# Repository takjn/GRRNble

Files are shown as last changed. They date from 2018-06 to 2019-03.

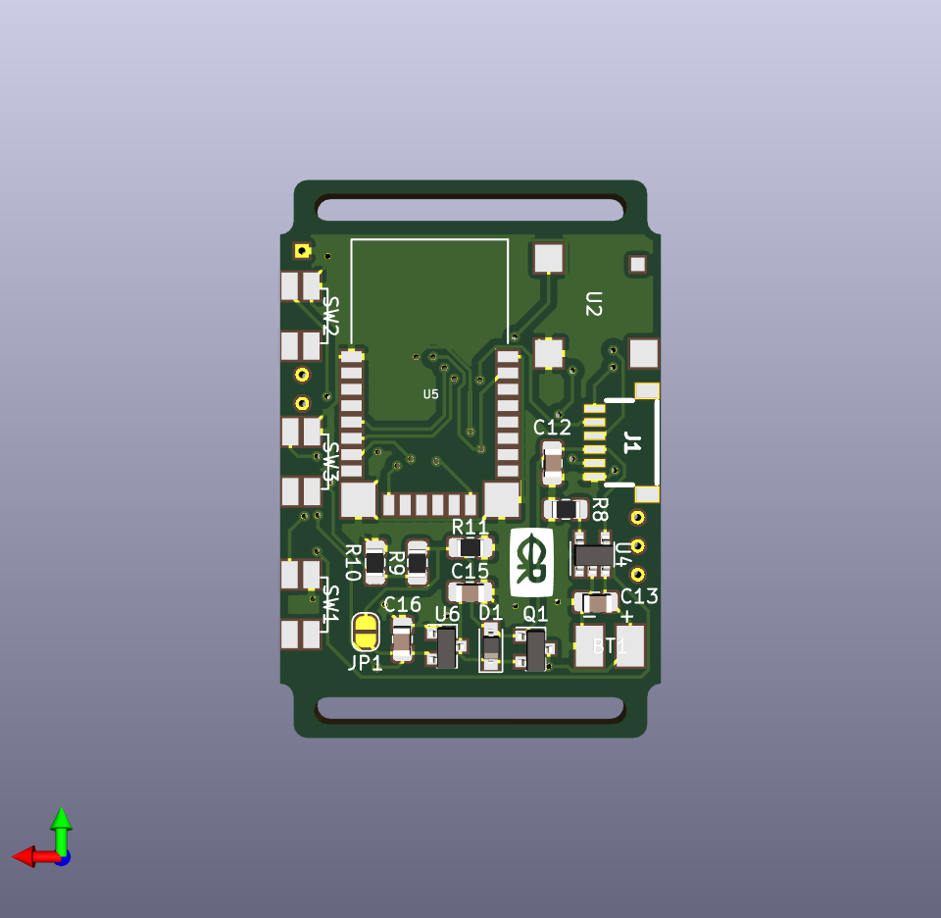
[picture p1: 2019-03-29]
pdf/back.png

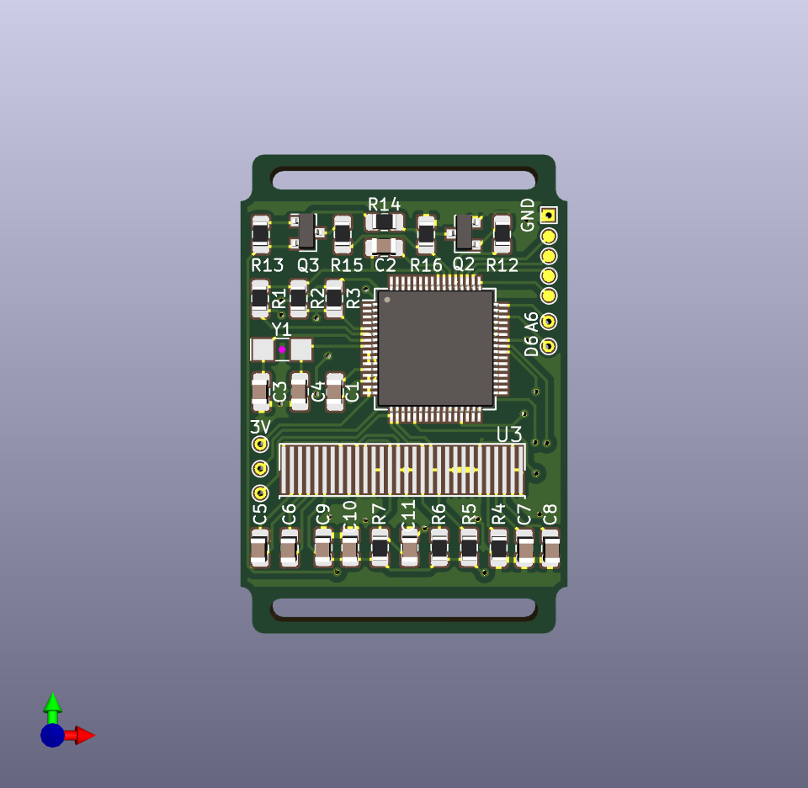
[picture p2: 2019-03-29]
pdf/front.png

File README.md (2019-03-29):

# GRRNble

DIY Smartwatch using Renesas RL78/G13 MCU and RN4020 ble module with Android companion app.

DIY Smartwatch (https://www.youtube.com/watch?v=k7GzKx2PxCo)

## Specification
### Hardware

- RL78/G13 32MHz (R5F100LJAFB 64pin LFQFP)
- ROM/RAM: 256KB/20KB
- 0.96″ 128x64 OLED display
- RN4020 Bluetooth Low Energy module
- RTC
- Buzzer
- Measuring battery voltage
- Li-Polymer Charging circuit

### Software

- Arduino like [IDE for GR](http://gadget.renesas.com/en/product/ide4gr.html) based smartwatch app
- [Android companion app](https://play.google.com/store/apps/details?id=com.github.takjn.grrnble)

## Hardware
### Schematic diagram
There is a KiCad project file in KiCad folder. Also, you can see the schematic pdf file in pdf folder.

### Parts list
All capacitors and resistors are 0805 (2012) SMD.

| Reference(s) | Value | Qty | Note |
|:---|:---|:---|:---|
|C1|0.47uF|1|I used 1.0uF insted.|
|C2, C11|0.1uF|2||
|C3, C4|15pF|2||
|C5, C6, C9, C10, C15, C16|1.0uF|6||
|C7, C12, C13|4.7uF|3||
|C8|2.2uF|1|I used 4.7uF insted.|
|R1|1k|1||
|R2|12k|1||
|R3|2k|1||
|R4|390k|1||
|R5, R6, R7, R13|10k|4||
|R8|22k|1||
|R9, R10|47k|2||
|R11|100k|1||
|R12, R14|100R|2||
|R15|7K5|1||
|R16|2K7|1||
|D1|CUS10F30|1||
|Q1, Q3|DMG3415U|2|P-ch FET|
|Q2|BSS138|1|N-ch FET|
|SW1, SW3, SW2|SKSCLAE010|3|ALPS Side Push switch|
|U1|R5F100LJAFB|1|RL78/G13 64pin|
|U2|UGCT7525AN4|1|Buzzer|
|U3|SSD1306|1|OLED 128x64 0.96 inch|
|U4|MCP73831-2-OT|1|Li-Polymer Charge Management Controller|
|U5|RN4020|1|Bluetooth Low Energy module|
|U6|MCP1703A-3302|1|LDO Regulator|
|Y1|FC-135|1|EPSON 3.2 x 1.5 x 0.80mm 32.768k crystal|
|BT1|Li-Po battery|1|3.7V/40mAh|
|J1|JST SH/1.0 6pin connector|1|JST 1.0mm pitch connector|
|-|JST SH/1.0 6pin cable|1|JST 1.0mm pitch terminal cable|
|-|FT232R / FT231X USB to serial adapter|1||

## Software

### RN4020 setup app

RN4020 can be setup with a special program and serial monitor.
Open RN4020Setup folder with [IDE for GR](http://gadget.renesas.com/en/product/ide4gr.html).
Connect your board and select GR-Cotton from "Tools" -> "Board" in the menu.
Compile the program and upload it to the board.

After uploading the sketch, select the port from "Tools" -> "Serial Port" in the menu and open Serial monitor.

### Smartwatch app

Open GRRNble folder with [IDE for GR](http://gadget.renesas.com/en/product/ide4gr.html).
Connect your board and select GR-Cotton from "Tools" -> "Board" in the menu.
Compile the program and upload it to the board.

### Android companion app

You need to have a development environment with Android Studio to build the Android App in the Android folder.

If you don't want to build from source files, you can install the compiled app from [Google Play](https://play.google.com/store/apps/details?id=com.github.takjn.grrnble).

## References
### Libraries
- [https://github.com/greiman/SSD1306Ascii](https://github.com/greiman/SSD1306Ascii)
- [https://github.com/Tamakichi/Arduino-misakiUTF16](https://github.com/Tamakichi/Arduino-misakiUTF16)

### Useful information (EN)
- [Gadget Renesas](http://gadget.renesas.com/en/)
- [GR-COTTON schematic diagram](http://gadget.renesas.com/ja/product/documents/gr-cotton_sch.pdf)
- [RN4020 Bluetooth® Low Energy Module User’s Guide](http://ww1.microchip.com/downloads/en/devicedoc/70005191b.pdf)
- [MCP1703A](http://akizukidenshi.com/download/ds/microchip/mcp1703a.pdf)
- [Designing A Li-Ion Battery Charger and Load Sharing System With
Microchip’s Stand-Alone Li-Ion Battery Charge Management Controller](http://ww1.microchip.com/downloads/en/appnotes/01149c.pdf)

### Useful information (JA)
- [Gadget Renesas](http://gadget.renesas.com/jp/)
- [GR-COTTON回路図](http://gadget.renesas.com/ja/product/documents/gr-cotton_sch.pdf)
- [RL78/G13 低消費電力動作編](https://www.renesas.com/jp/ja/doc/products/mpumcu/apn/rl78/001/r01an0465jj0210_rl78.pdf)
- [RN4020 Bluetooth® Low Energy モジュールユーザガイド](http://akizukidenshi.com/download/ds/microchip/70005191A_JP.pdf)
- [MCP1703A](http://akizukidenshi.com/download/ds/microchip/mcp1703a.pdf)
- [マイクロチップのスタンドアロンリチウムイオンバッテリ充電管理コントローラを使用したリチウムイオンバッテリ充電回路および負荷分担システムの設計](http://ww1.microchip.com/downloads/en/AppNotes/DS01149C_JP_battery.pdf)
- [BLE通信ソフトを作る ( Android Studio 2.3.3 + RN4020 )](http://www.hiramine.com/programming/blecommunicator/index.html)
- [KiCadで雑に基板を作る チュートリアル](https://www.slideshare.net/soburi/kicad-53622272)

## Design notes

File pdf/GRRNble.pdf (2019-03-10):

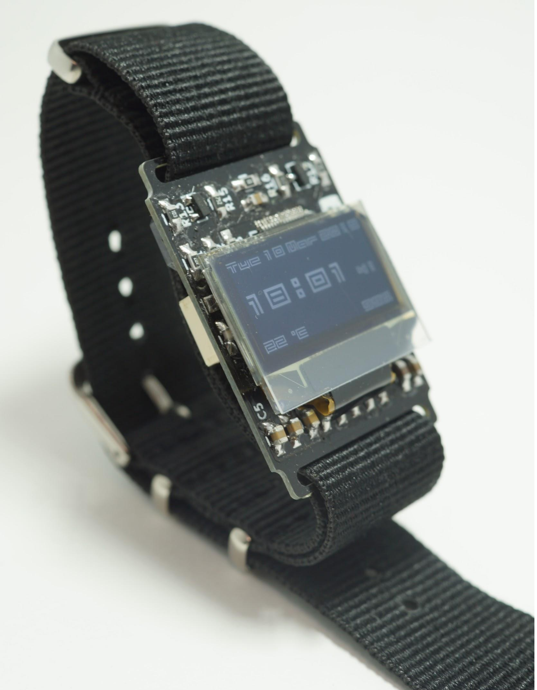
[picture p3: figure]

# DIY Smartwatch

### GRRNble Gen2

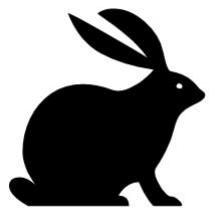
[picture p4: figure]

# @takjn

### https://github.com/takjn/GRRNble

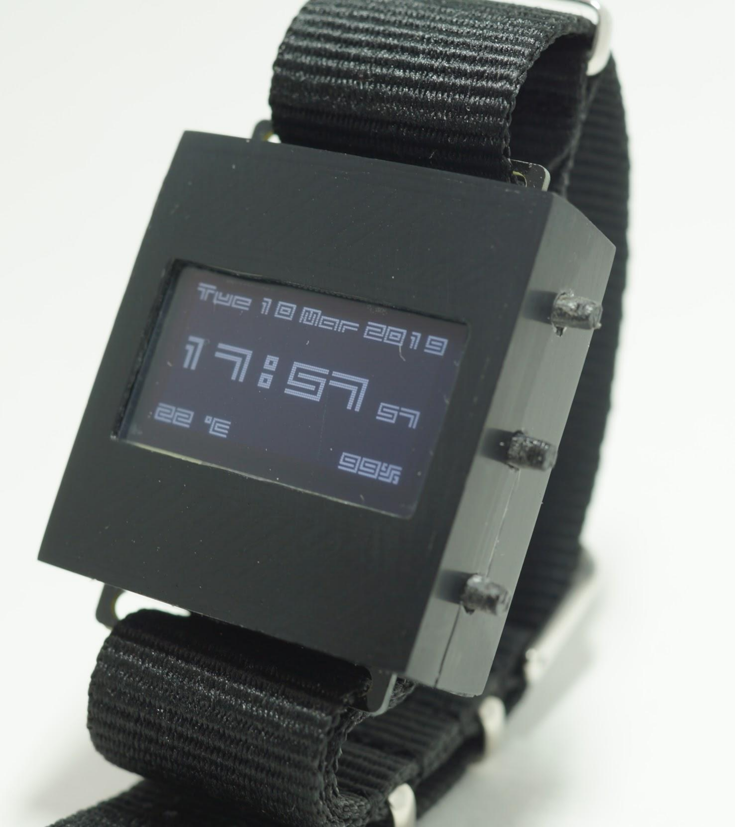
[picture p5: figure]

# Specification

### - RL78/G13 (R5F100LJAFB 64pin) - OLED (SSD1306), BLE (RN4020) - GR-COTTON ベースの基板 - IDE for GR で書き込み可能

- 3Dプリンターによる筐体
- Androidアプリと連携した通知
- バッテリーは1日は持つ

# Gen2 - 細かい点を色々と改良

### •RN4020 (BLE) の処理をポーリングから割り込みに変更

## •SSD1306 (OLED) の消費電力削減

### •ケースの改良 - 3Dプリント + UVレジンによるコーティング

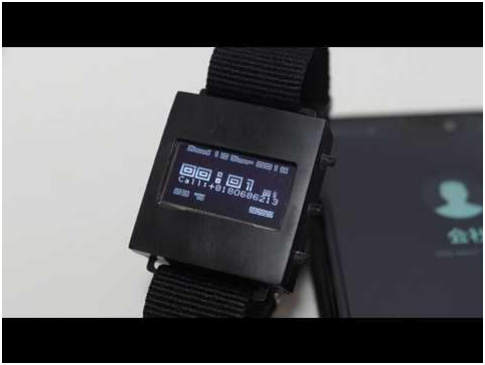
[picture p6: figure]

## Demonstration

https://youtu.be/k7GzKx2PxCo

- 電話の着信通知
- メニュー
- スタンバイ画面

# Hardware

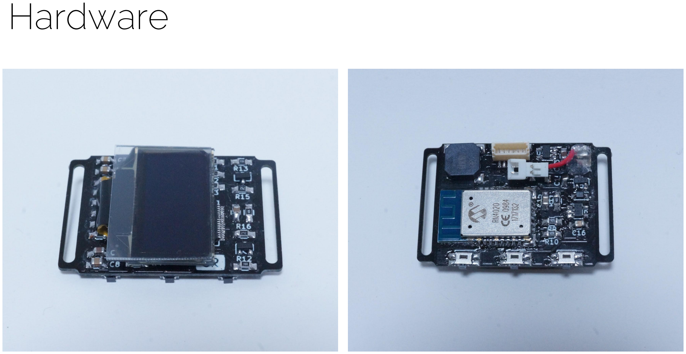
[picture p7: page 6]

# Software

## - RN4020 は deep sleep mode で待機

- スクリプト機能を活用してキャラクタリスティックをIOポートに紐付け
- スマホアプリからの受信でデジタルIOピンを HIGH にできる (割り込み)
- 受信内容はRN4020が保持しているのでマイコンが復帰後に Read できる

## - RL78/G13 は PM_STOP_MODE で待機

- delay()関数を実行しながらループで待機する
- RN4020 からの割り込みで復帰し、受信した結果を Read する
- ディスプレイ (OLED) の消費電力削減が課題

# Watch Case

### - 3Dプリンターで作成し、表面をUVレジンでコーティング

### - UVレジンを使うことで簡単に積層痕を消すことができる

- 3Dプリントしたものに軽くヤスリをかける
- UVレジンを厚塗りする (積層痕を埋める)
- UVランプでUVレジンを固めた後、紙ヤスリとコンパウンドで磨く (#240, #400, #800, #1200, #2000, 細目, 仕上げ目)

### - 磨きやすい硬さなので、簡単に仕上がる

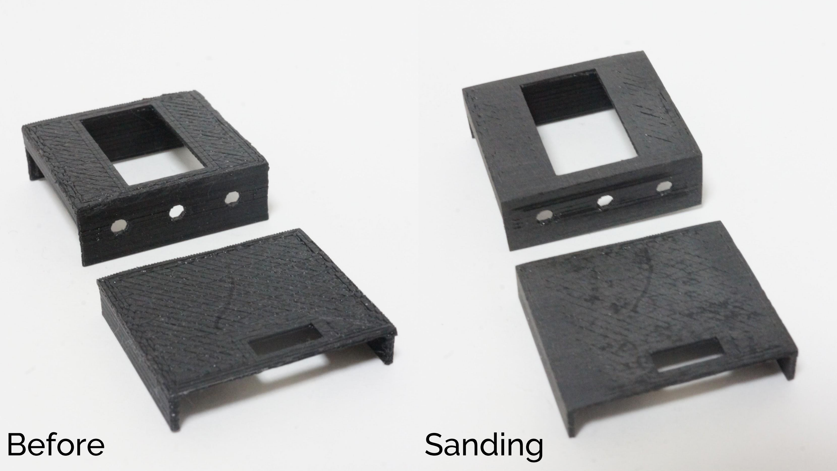
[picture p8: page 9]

Before | Sanding

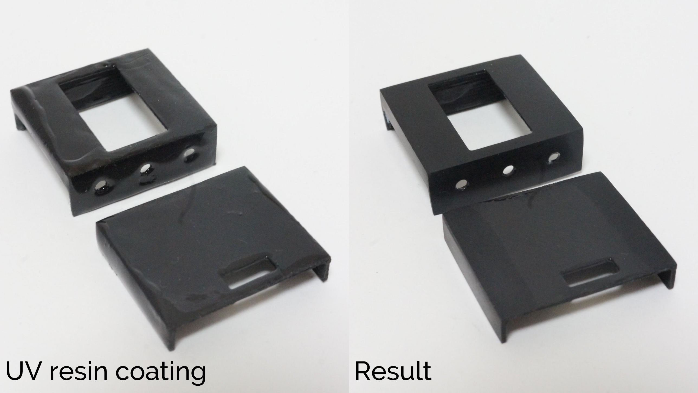
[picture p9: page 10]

UV resin coating | Result

# DIY Smartwatch

### GRRNble Gen2

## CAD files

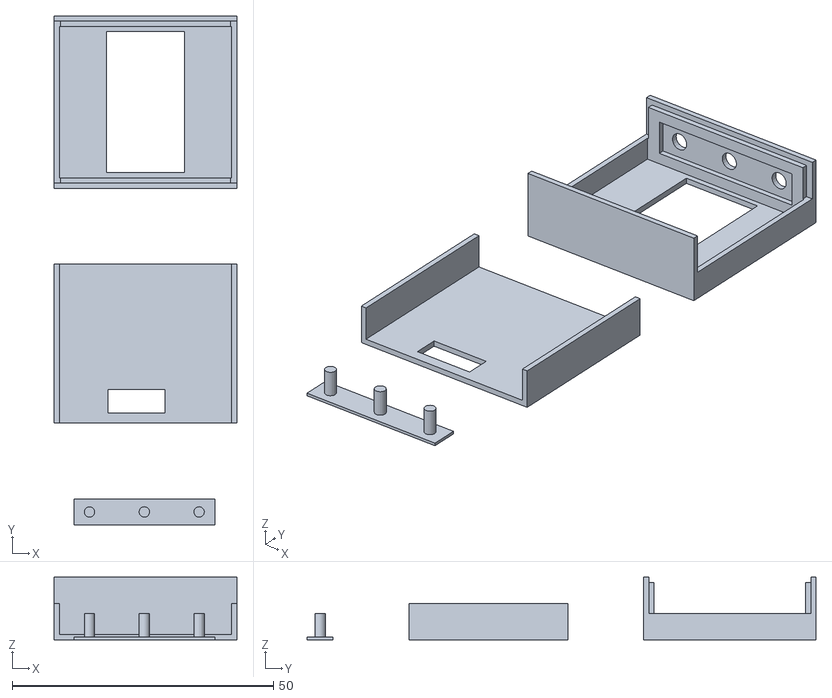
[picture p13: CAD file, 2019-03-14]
stl/GRRNble.stl
35.0 x 97.5 x 12.0

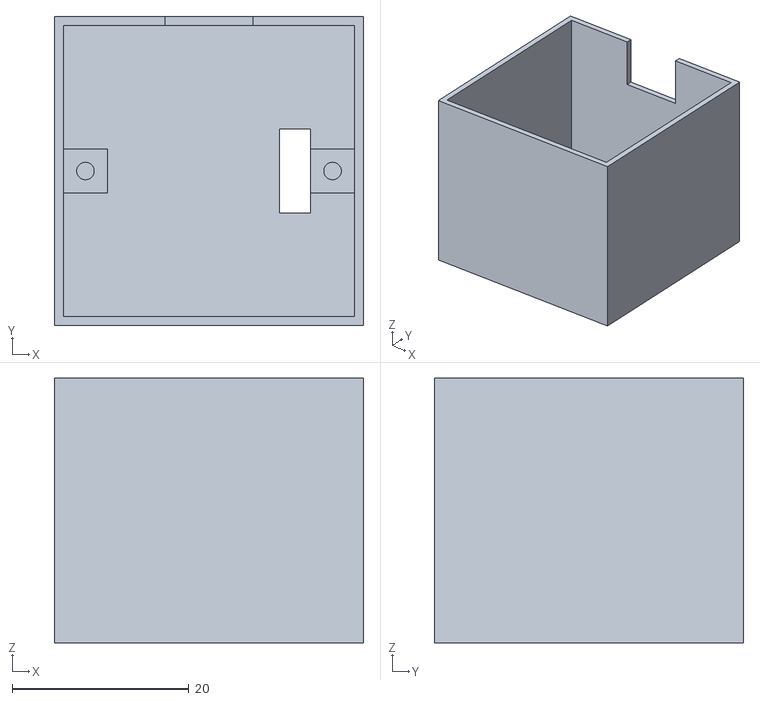
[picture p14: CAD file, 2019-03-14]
stl/GRRNbleCase.stl
35.0 x 35.0 x 30.0

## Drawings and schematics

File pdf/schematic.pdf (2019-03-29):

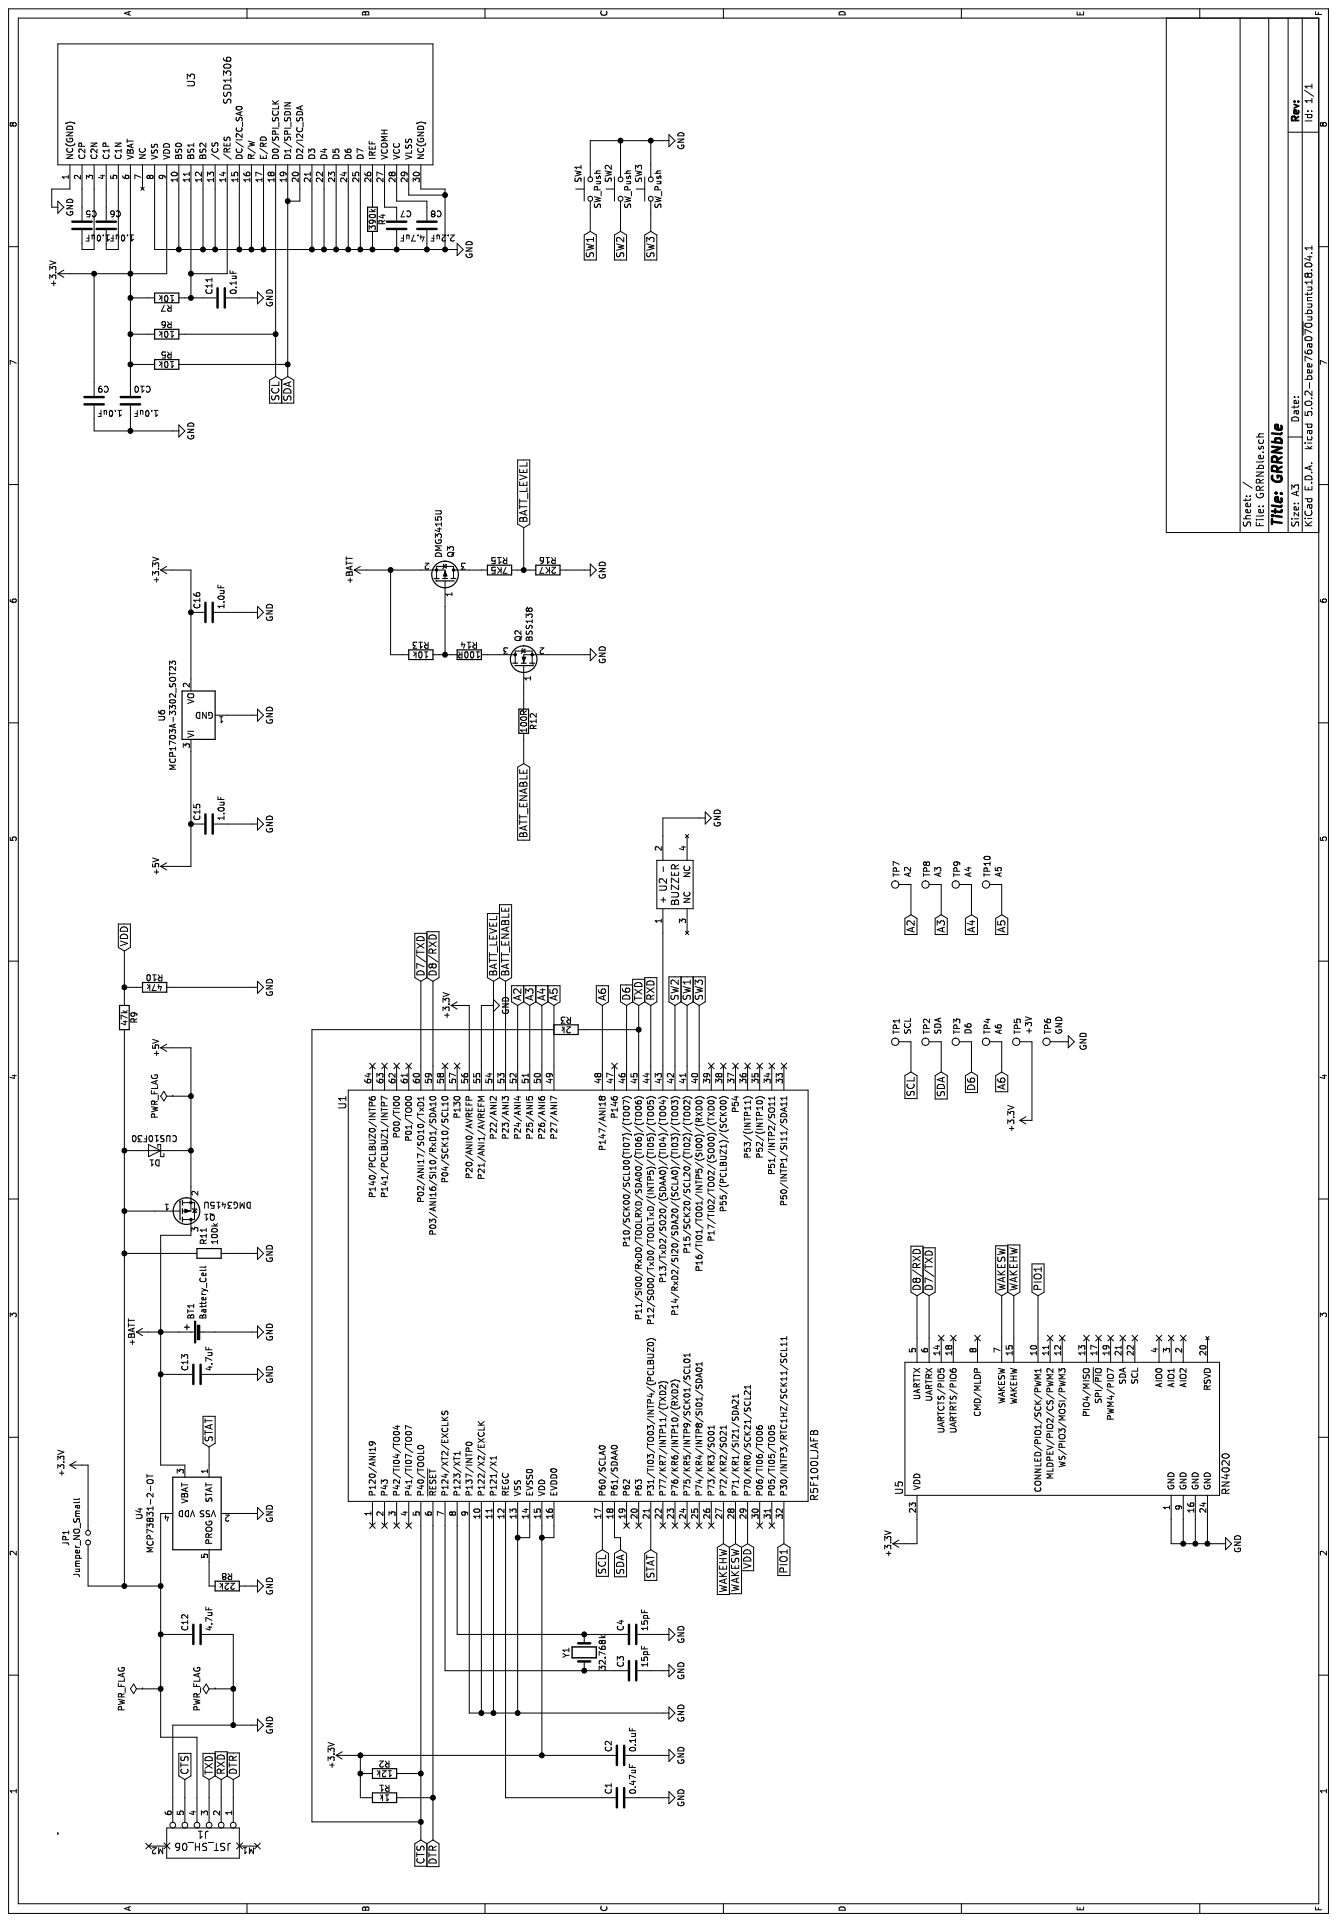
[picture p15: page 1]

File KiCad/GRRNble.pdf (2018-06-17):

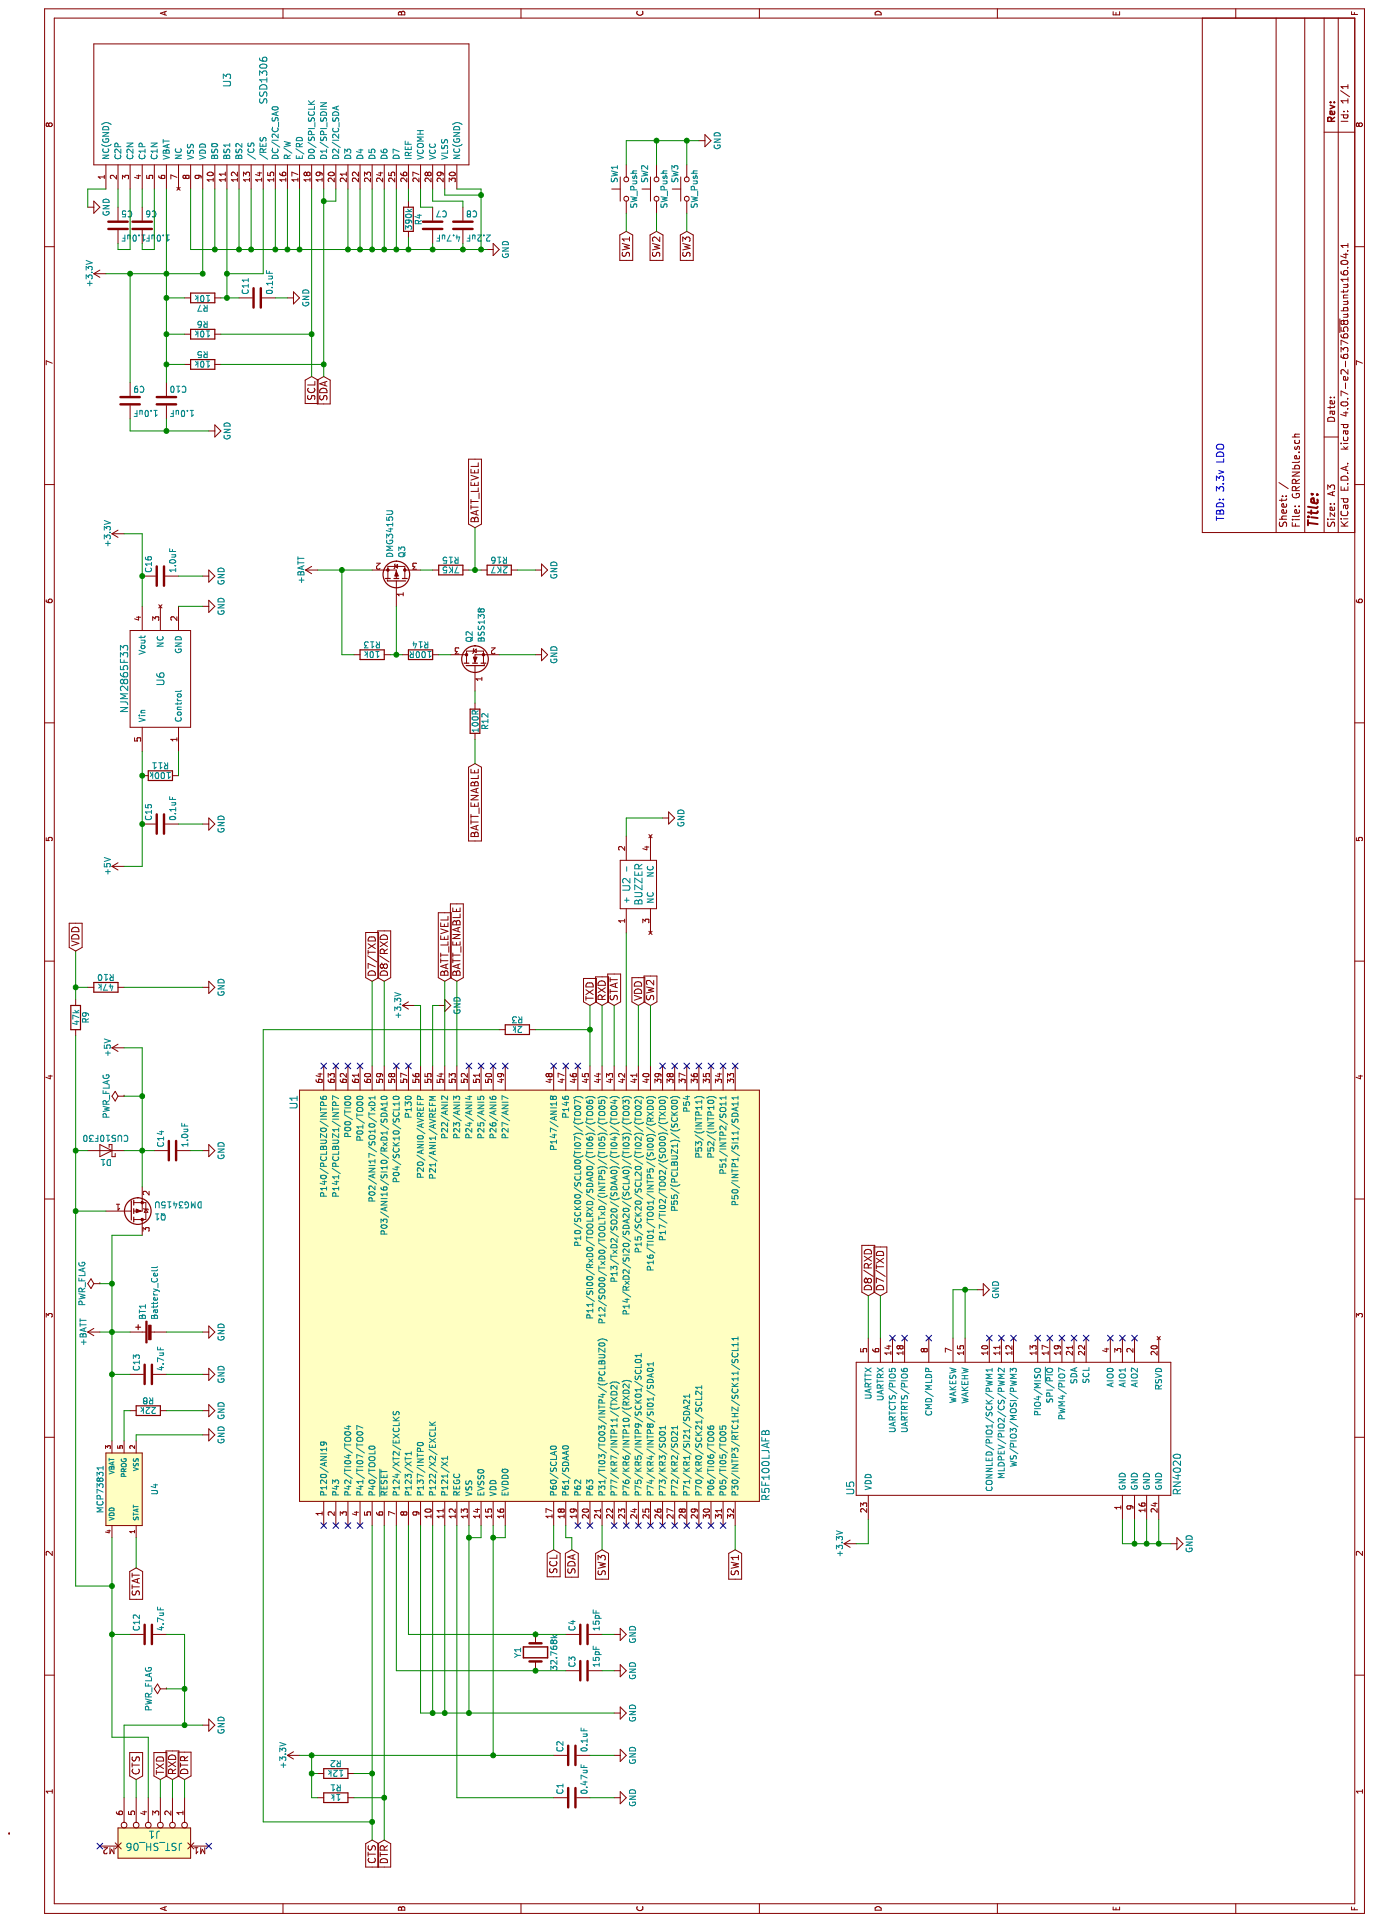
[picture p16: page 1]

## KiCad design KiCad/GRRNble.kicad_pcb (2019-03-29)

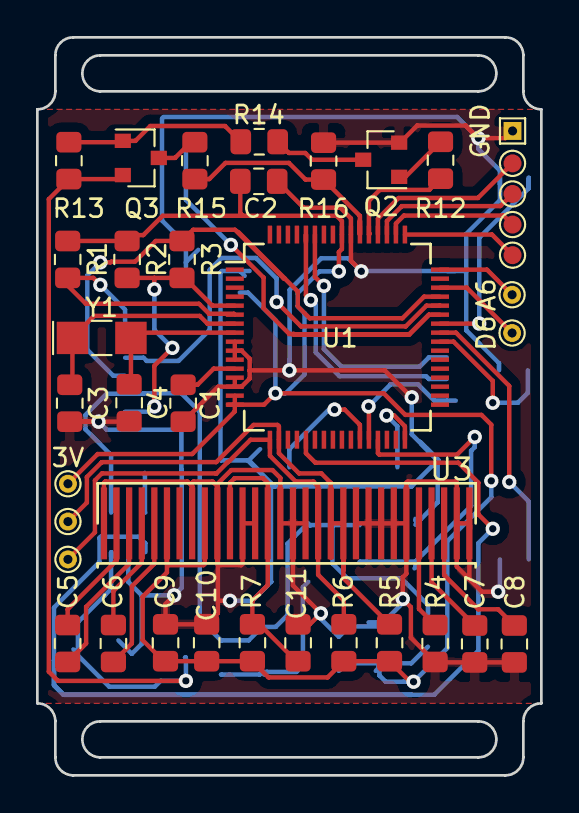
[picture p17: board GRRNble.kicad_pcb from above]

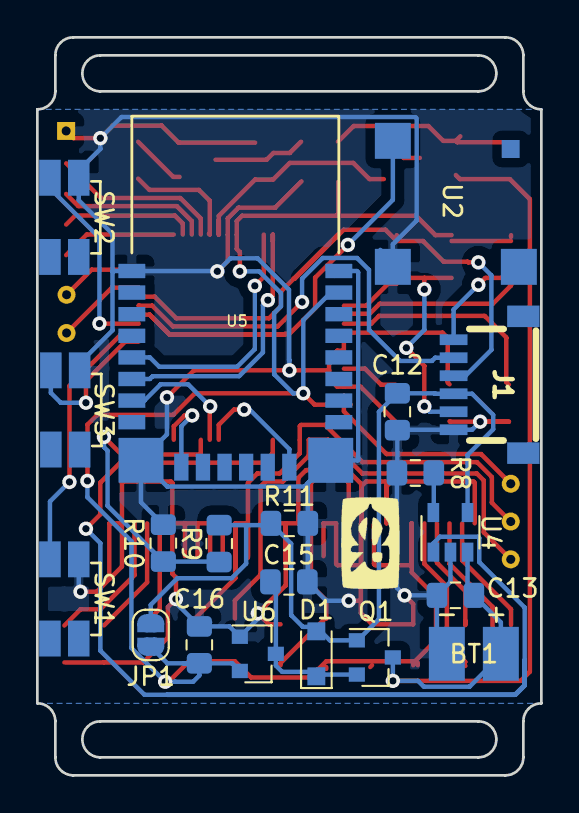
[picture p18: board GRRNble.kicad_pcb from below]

Board: 2 copper layers, 28.0 x 41.0 mm, 58 parts (20 on the bottom side), 46 nets.

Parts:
3V: +3V; TestPoint_THTPad_D1.0mm_Drill0.5mm
A2: A2; TestPoint_Pad_D1.0mm
A3: A3; TestPoint_Pad_D1.0mm
A4: A4; TestPoint_Pad_D1.0mm
A5: A5; TestPoint_Pad_D1.0mm
A6: A6; TestPoint_THTPad_D1.0mm_Drill0.5mm
BT1: Battery_Cell; BatteryPad
C1: 0.47uF; C_0805_2012Metric_Pad1.15x1.40mm_HandSolder
C2, C11: 0.1uF; C_0805_2012Metric_Pad1.15x1.40mm_HandSolder
C3, C4: 15pF; C_0805_2012Metric_Pad1.15x1.40mm_HandSolder
C5, C6, C9, C10, C15, C16: 1.0uF; C_0805_2012Metric_Pad1.15x1.40mm_HandSolder
C7, C12, C13: 4.7uF; C_0805_2012Metric_Pad1.15x1.40mm_HandSolder
C8: 2.2uF; C_0805_2012Metric_Pad1.15x1.40mm_HandSolder
D1: CUS10F30; D_SOD-323_HandSoldering
D6: D6; TestPoint_THTPad_D1.0mm_Drill0.5mm
GND: GND; TestPoint_THTPad_1.0x1.0mm_Drill0.5mm
J1: JST_SH_06; JST-SM-06B-SRSS-TB
JP1: Jumper_NO_Small; SolderJumper-2_P1.3mm_Open_RoundedPad1.0x1.5mm
Q1, Q3: DMG3415U; SOT-23
Q2: BSS138; SOT-23
R1: 1k; R_0805_2012Metric_Pad1.15x1.40mm_HandSolder
R2: 12k; R_0805_2012Metric_Pad1.15x1.40mm_HandSolder
R3: 2k; R_0805_2012Metric_Pad1.15x1.40mm_HandSolder
R4: 390k; R_0805_2012Metric_Pad1.15x1.40mm_HandSolder
R5, R6, R7, R13: 10k; R_0805_2012Metric_Pad1.15x1.40mm_HandSolder
R8: 22k; R_0805_2012Metric_Pad1.15x1.40mm_HandSolder
R9, R10: 47k; R_0805_2012Metric_Pad1.15x1.40mm_HandSolder
R11: 100k; R_0805_2012Metric_Pad1.15x1.40mm_HandSolder
R12, R14: 100R; R_0805_2012Metric_Pad1.15x1.40mm_HandSolder
R15: 7K5; R_0805_2012Metric_Pad1.15x1.40mm_HandSolder
R16: 2K7; R_0805_2012Metric_Pad1.15x1.40mm_HandSolder
SCL: SCL; TestPoint_THTPad_D1.0mm_Drill0.5mm
SDA: SDA; TestPoint_THTPad_D1.0mm_Drill0.5mm
SW1, SW2, SW3: SW_Push; SKSC
U1: R5F100LJAFB; LQFP-64_10x10mm_P0.5mm
U2: BUZZER; BZ7025_3pin
U3: SSD1306
U4: MCP73831-2-OT; SOT-23-5
U5: RN4020
U6: MCP1703A-3302_SOT23; SOT-23
Y1: 32.768k; Crystal_SMD_G8-2Pin_3.2x1.5mm_HandSoldering

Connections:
+3V3: 3V.1, C2.1, C9.1, C10.1, C16.1, JP1.2, R1.1, R2.1, R5.1, R6.1, R7.2, U1.15, U1.16, U1.56, U3.6, U3.9, U5.23, U6.2
+5V: C15.1, D1.1, Q1.2, U6.3
+BATT: BT1.1, C13.1, Q1.3, Q3.2, R13.1, U4.3
A2: A2.1, U1.52
A3: A3.1, U1.51
A4: A4.1, U1.50
A5: A5.1, U1.49
A6: A6.1, U1.48
BATT_ENABLE: R12.2, U1.53
BATT_LEVEL: R15.2, R16.1, U1.54
CTS: J1.5, R2.2, R3.1, U1.5
D6: D6.1, U1.46
D7/TXD: U1.60, U5.6
D8/RXD: U1.59, U5.5
DTR: J1.1, R1.2, U1.6
GND: BT1.2, C1.2, C2.2, C3.2, C4.2, C7.2, C8.2, C9.2, C10.2, C11.2, C12.2, C13.2, C15.2, C16.2, GND.1, J1.6, Q2.2, R4.2, R8.2, R10.2, R11.2, R16.2, SW1.2, SW2.2, SW3.2, U1.9, U1.10, U1.11, U1.13, U1.14, U1.55, U2.2, U3.1, U3.8, U3.10, U3.12, U3.13, U3.15, U3.16, U3.17, U3.21, U3.22, U3.23, U3.24, U3.25, U3.29, U3.30, U4.2, U5.1, U5.9, U5.16, U5.24, U6.1
unnamed: C1.1, U1.12
unnamed: C3.1, U1.7, Y1.1
unnamed: C4.1, U1.8, Y1.2
unnamed: C5.1, U3.2
unnamed: C5.2, U3.3
unnamed: C6.1, U3.4
unnamed: C6.2, U3.5
unnamed: C7.1, U3.27
unnamed: C8.1, U3.28
unnamed: C11.1, R7.1, U3.11, U3.14
unnamed: C12.1, D1.2, J1.4, JP1.1, Q1.1, R9.2, R11.1, U4.4
unnamed: Q2.1, R12.1
unnamed: Q2.3, R14.2
unnamed: Q3.1, R13.2, R14.1
unnamed: Q3.3, R15.1
unnamed: R4.1, U3.26
unnamed: R8.1, U4.5
unnamed: U1.43, U2.1
PIO1: U1.32, U5.10
RXD: J1.2, U1.44
SCL: R6.2, SCL.1, U1.17, U3.18
SDA: R5.2, SDA.1, U1.18, U3.19, U3.20
STAT: U1.21, U4.1
SW1: SW1.1, U1.41
SW2: SW2.1, U1.42
SW3: SW3.1, U1.40
TXD: J1.3, R3.2, U1.45
VDD: R9.1, R10.1, U1.29
WAKEHW: U1.27, U5.15
WAKESW: U1.28, U5.7

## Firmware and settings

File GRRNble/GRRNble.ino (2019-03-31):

#include <Arduino.h>
#include <RTC.h>
#include <Wire.h>
#include <stdlib.h>

#include "SSD1306Ascii.h"
#include "SSD1306AsciiWire.h"

//#define DEBUG 1

// setting for SSD1306
SSD1306AsciiWire oled;
#define I2C_ADDRESS 0x3C

// settings for I/O pins
#define BUZZER_PIN      9           // pin for buzzer
#define KEY_PREV_PIN    10          // pin for previous button
#define KEY_SELECT_PIN  3           // pin for select button
#define KEY_NEXT_PIN    5           // pin for next button
#define VOLTAGE_OUT_PIN A1          // pin for voltage measurement
#define VOLTAGE_CHK_PIN A0          // pin for voltage measurement
#define WAKEHW_PIN  11              // pin for RN4020 WAKEHW
#define WAKESW_PIN  12              // pin for RN4020 WAKESW
#define PIO1_PIN 2                  // pin for RN4020 PIO1
#define USB_STAT_PIN 13             // pin for USB status
#define CHG_STAT_PIN 4              // pin for charging status

// settings for buzzer
const uint8_t BUZZER_VOLUMES[4] = { 0, 1, 5, 15 };  // 4 steps volume (0=silence)
int buzzer_volume = 3;                              // initial volume index

// settings for display
const int DISPLAY_CONTRASTS[4] = { 0, 50, 128, 255 };  // 4 steps contrast
int display_contrast = 3;
boolean display_always_on = true;

// settings for power saving
const unsigned long DELAY_SLEEPS[4] = {0, 10000, 5000, 3000};  // sleep (millisec, 0=always on)
int delay_sleep = 3;
boolean is_active = true;

// settings for battery service
#define MAX_VOLTAGE 3.7
#define MAX_VOLTAGE_DROP 0.5
int voltage = 0;
int is_usb_connected = 0;
int is_charging = 0;

// settings for temperature service
double temperature = getTemperatureWithClockControl(TEMP_MODE_CELSIUS);

// variables for watch
RTC_TIMETYPE datetime = {15, 12, 31, 2, 23, 59, 30};

// variables for notification
String message = "";
bool has_notice = false;

// variables for power saving
unsigned long last_millis = 0;

// mode
#define MODE_TIME 0        // Watch
#define MODE_MENU 1        // Menu
#define MODE_SETTIME 2     // Set Date & Time
#define MODE_GAME 3        // Game
uint8_t mode_current = MODE_TIME;

// key code
#define KEY_NONE 0
#define KEY_PREV 1
#define KEY_NEXT 2
#define KEY_SELECT 3

void wakeupInterrupt() {
  is_active = true;
}

void notificationInterrupt() {
  if (has_notice == false) has_notice = true;
  wakeupInterrupt();
}

void setup() {
  // initialize pins
  pinMode(VOLTAGE_OUT_PIN, OUTPUT);
  pinMode(VOLTAGE_CHK_PIN, INPUT);
  pinMode(BUZZER_PIN, OUTPUT);
  pinMode(KEY_PREV_PIN, INPUT_PULLUP);
  pinMode(KEY_SELECT_PIN, INPUT_PULLUP);
  pinMode(KEY_NEXT_PIN, INPUT_PULLUP);
  pinMode(PIO1_PIN, INPUT);
  pinMode(WAKESW_PIN, OUTPUT);
  pinMode(WAKEHW_PIN, OUTPUT);
  pinMode(USB_STAT_PIN, INPUT);
  pinMode(CHG_STAT_PIN, INPUT);

  // initialize RTC
  rtc_init();
  SUBCUD.subcud = 0xB8;  // http://japan.renesasrulz.com/gr_user_forum_japanese/f/gr-kurumi/631/gr-kurumi-rtc
  
  // initialize SSD1306
  Wire.begin();     
  oled.begin(&Adafruit128x64, I2C_ADDRESS);
  oled.setContrast(DISPLAY_CONTRASTS[display_contrast]);
  oled.clear();
  // Set Pre-charge period for energy saving
  oled.ssd1306WriteCmd(SSD1306_SETPRECHARGE);
  oled.ssd1306WriteCmd(0x00);  // 0xF1(default)
  oled.ssd1306WriteCmd(SSD1306_SETVCOMDETECT);
  oled.ssd1306WriteCmd(0x00);  // 0x00, 0x20, 0x30, 0x40 (default)

  // initialize RN4020
  digitalWrite(WAKESW_PIN, LOW);
  digitalWrite(WAKEHW_PIN, LOW);

#ifdef DEBUG
  // initialize debuging port
  Serial.begin(115200);
#endif

  // wakeup interrupt
  attachInterrupt(0, notificationInterrupt, RISING);
  attachInterrupt(1, wakeupInterrupt, CHANGE);

  // setup power management
  setPowerManagementMode(PM_STOP_MODE);
  last_millis = millis();

  // notify sensors status
  rtc_attach_constant_period_interrupt_handler(periodInterrupt);
  rtc_set_constant_period_interrupt_time(RTC_CONSTANT_PERIOD_TIME_1MINUTE);
  rtc_constant_period_interrupt_on();  
}

boolean period_interrupt_flag = true;
void periodInterrupt() {
  period_interrupt_flag = true;
}

void sleep() {
  oled.set1X();
  oled.clear();
  if (display_always_on == true) {
    drawSmallWatch();
  } else {
    // Set Display off
    oled.ssd1306WriteCmd(0x0ae);
    // Disable charge pump
    oled.ssd1306WriteCmd(SSD1306_CHARGEPUMP);
    oled.ssd1306WriteCmd(0x10);
  }

  is_active = false;
}

void wakeup() {
  if (display_always_on == false) {
    // Enable charge pump
    oled.ssd1306WriteCmd(SSD1306_CHARGEPUMP);
    oled.ssd1306WriteCmd(0x14);
    // Set Display on
    oled.ssd1306WriteCmd(0x0af);
  }
  oled.clear();
  
  is_active = true;
  last_millis = millis();
  mode_current = MODE_TIME;
}

void loop() {
  unsigned char key;
  
  // stanby loop
  if (is_active == false) {
    while(is_active == false) {
      if (period_interrupt_flag) {
        notifyBLE();
        period_interrupt_flag = false;

        if (display_always_on == true) {
          drawSmallWatch();
        }
      }
      _STOP();
    }
    wakeup();
  }

  // check buttons
  key = key_read();
  if (key != KEY_NONE) {
    last_millis = millis();
  }

  // check BLE
  if (has_notice == true) {
    setPowerManagementMode(PM_NORMAL_MODE);
    boolean result = checkBLE();
    if (result == true) {
      alert();
    }
    setPowerManagementMode(PM_STOP_MODE);
    has_notice = false;
    last_millis = millis();
  }

  // notify sensors status
  if (period_interrupt_flag) {
    notifyBLE();
    period_interrupt_flag = false;
  }

  // draw screen
  if (mode_current == MODE_TIME) {
    drawWatch(key);
  } else if (mode_current == MODE_MENU) {
    drawMenu(key);
  } else if (mode_current == MODE_SETTIME) {
    drawSetTime(key);
  } else if (mode_current == MODE_GAME) {
    startGame();
    oled.clear();
    mode_current = MODE_TIME;
    last_millis = millis();
  }

  // delay  
  delay(50);
  
  // sleep if idle
  if(delay_sleep > 0 && (millis() - last_millis) > DELAY_SLEEPS[delay_sleep]) {
    sleep();
  }
}

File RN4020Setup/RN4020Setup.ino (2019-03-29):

/**
  GRRNble - RN4020 setup program

  Copyright (c) 2019 Jun Takeda

  This software is released under the MIT License.
  http://opensource.org/licenses/mit-license.php
*/

#include <Arduino.h>

// pin assignments
#define KEY_PREV_PIN    10          // pin for previous button
#define KEY_SELECT_PIN  3           // pin for select button
#define KEY_NEXT_PIN    5           // pin for next button
#define WAKEHW_PIN  11              // pin for RN4020 WAKEHW
#define WAKESW_PIN  12              // pin for RN4020 WAKESW
#define PIO1_PIN 2                  // pin for RN4020 PIO1

// key code
#define KEY_NONE 0
#define KEY_PREV 1
#define KEY_NEXT 2
#define KEY_SELECT 3


int waitKeyIn() {
  while (digitalRead(KEY_SELECT_PIN) != 0 && digitalRead(KEY_PREV_PIN) != 0 && digitalRead(KEY_NEXT_PIN) != 0);

  if (digitalRead(KEY_SELECT_PIN) == 0) {
    while (digitalRead(KEY_SELECT_PIN) == 0);
    return KEY_SELECT;
  } else if (digitalRead(KEY_PREV_PIN) == 0) {
    while (digitalRead(KEY_PREV_PIN) == 0);
    return KEY_PREV;
  } else if (digitalRead(KEY_NEXT_PIN) == 0) {
    while (digitalRead(KEY_NEXT_PIN) == 0);
    return KEY_NEXT;
  }
  
  return KEY_NONE;
}

void readFromRN4020() {
  while (Serial1.available()) {
    int inByte = Serial1.read();
    Serial.write(inByte); 
    delay(5);
  }
}

void sendToRN4020(String command) {
  Serial1.println(command);
  Serial1.flush();
  delay(500);
  readFromRN4020();
}

void setupRN4020() {
  sendToRN4020("SF,2");            // Factory reset
  sendToRN4020("SN,GRRNble");      // Set name
  sendToRN4020("SB,0");            // Set 2400bps

  sendToRN4020("SS,C0000001");     // Enable device information, battery, private service
  sendToRN4020("SR,25002000");     // Set the device as periferal (Auto Advertise, No Direct Advertisement, Run script after power on)
  sendToRN4020("ST,0010,0004,0258");    // Set interval, latency and timeout
  sendToRN4020("PZ");              // Clear the current private service and characteristics

  // Set private service UUID
  sendToRN4020("PS,3B382559223F48CA81B4E151598F661B");

  // Add private characteristic to current private service.
  // The property of this characteristic is 0x12 (readble and could notify) and has a maximum data size of 2 bytes.
  sendToRN4020("PC,DB5445C44A70442287AF81D35456BEB5,12,02");

  // The property of this characteristic is 0x0A (readble and writable) and has a maximum data size of 20 bytes.
  sendToRN4020("PC,B23324431DD3407BB3E65D349CAF5368,0A,14");
  sendToRN4020("PC,E2B8D854BFA64E798A5326B07604597D,0A,14");

  // The property of this characteristic is 0x04 (writable) and has a maximum data size of 1 bytes.
  sendToRN4020("PC,4344EEE2C4674318BFAB7564815A5DB8,04,01");

  sendToRN4020("WC");              // Clear script
  sendToRN4020("WW");              // Enter script input mode

  // write RN4020 script
  sendToRN4020("@PW_ON");          // handle power on event
  sendToRN4020("|O,01,%001F");     // associate handle 0x001F to PIO1

  // send the “ESC” key to exit from script input mode.
  Serial1.write(0x1b);
  Serial1.flush();

  sendToRN4020("R,1");             // Reboot RN4020 to make the changes effective

  Serial1.begin(2400);
  delay(1000);
  sendToRN4020("WP");              // Pause script

  sendToRN4020("D");               // Dump configuration
  sendToRN4020("LS");              // list the services on server side. Private service and characteristics could be found in the list
  sendToRN4020("LW");              // Show script
}

void showMenu() {
  Serial.println("--------------------------------------------------------------------------------");
  Serial.println("GRRNble RN4020 setup program");
  Serial.println("--------------------------------------------------------------------------------");
  Serial.println("To connect with RN4020 at 115200 bps(default), push the top button.");
  Serial.println("To connect with RN4020 at 2400 bps, push the bottom button.");

  int key = waitKeyIn();
  if (key == KEY_NEXT) {
    Serial1.begin(2400);
    Serial.println("2400 bps is selected.");
  } else {
    Serial.println("115200 bps is selected.");
  }
  Serial.println("");
  sendToRN4020("WP");
  sendToRN4020("D");
  Serial.println("");

  Serial.println("To setup, push the top button.");
  Serial.println("To communicate with RN4020, push the bottom button.");
  Serial.println("To restart, push the center button.");

  key = waitKeyIn();
  if (key == KEY_PREV) {
    Serial.println("Starting setup.");
    setupRN4020();
  }
  if (key == KEY_SELECT) {
    softwareReset();
  } 

  Serial.println("");
}

bool interrupted = false;
void debugInterrupt() {
  interrupted = true;
}

void setup() {
  pinMode(KEY_PREV_PIN, INPUT_PULLUP);
  pinMode(KEY_SELECT_PIN, INPUT_PULLUP);
  pinMode(KEY_NEXT_PIN, INPUT_PULLUP);

  // set RN4020 power status
  pinMode(PIO1_PIN, INPUT);
  pinMode(WAKEHW_PIN, OUTPUT);
  pinMode(WAKESW_PIN, OUTPUT);
  digitalWrite(WAKEHW_PIN, LOW);
  digitalWrite(WAKESW_PIN, HIGH);

  Serial.begin(115200);
  Serial1.begin(115200);

  showMenu();

  attachInterrupt(0, debugInterrupt, RISING);
  Serial.println("Done.You can communicate with RN4020.");
}

void loop() {
  // read from port 1, send to port 0:
  if (Serial1.available()) {
    int inByte = Serial1.read();
    Serial.write(inByte); 
  }
  
  // read from port 0, send to port 1:
  if (Serial.available()) {
    int inByte = Serial.read();
    Serial1.write(inByte); 
  }

  if (interrupted) {
    interrupted = false;
    Serial.println("triggered");
    sendToRN4020("WP");             // Pause script
    sendToRN4020("SHW,001F,00");    // Reset characteristic value
    sendToRN4020("|O,01,00");       // Reset pio0 value
    sendToRN4020("SHR,001B");       // Read characteristic value
    sendToRN4020("WR");             // Run script
  }
}

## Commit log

2018-05-27 add device list
2018-05-30 add KiCad project
    [GRRNble.kicad_pcb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]
2018-06-01 add Battery level service
2018-06-04 add battery level
2018-06-05 add temperature service
2018-06-09 change pin assign
2018-06-13 WIP (PCB)
    [GRRNble.kicad_pcb, _saved_GRRNble.sch]
2018-06-14 update PCB
    [GRRNble.kicad_pcb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]
2018-06-20 set power management mode
2018-06-21 add disable charge pump
2018-06-21 improve power consumption
2018-07-03 bug fix
    [GRRNble.kicad_pcb]
2018-07-13 fix max voltage
2019-02-14 change schematic layout
    [GRRNble-2019-02-14-20-21-08.sch, GRRNble.kicad_pcb]
2019-02-14 change PCB status
    [GRRNble.kicad_pcb, GRRNble.sch]
2019-02-14 change PCB layout
    [GRRNble.kicad_pcb, GRRNble.sch]
2019-02-14 update gerber files
    [GRRNble.kicad_pcb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]
2019-03-01 change pin assignments
2019-03-01 fix SSD1306 power off sequence
    [GRRNble.ino]
2019-03-04 add schematic
    [GRRNble.sch]
2019-03-14 add STL files
    [GRRNble.stl, GRRNbleCase.stl]
2019-03-20 WIP:Change schematic
    [GRRNble.kicad_pcb, GRRNble.sch]
2019-03-22 change PIN assignment
2019-03-22 update schematic pdf
2019-03-22 add PCB images
